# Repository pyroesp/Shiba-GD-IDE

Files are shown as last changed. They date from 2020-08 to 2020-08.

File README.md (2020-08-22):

# Shiba GD-IDE

The Sega Dreamcast uses a GD-ROM Optical Drive to read the game discs. Some clever people discovered that the optical drive uses connections similar to an IDE HDD.  
If you look for *Dreamcast HDD mod* on Google Images you'll see some crazy stuff. People were just soldering 40 pin flat ribbon cables to the motherboard or optical drive directly, which looks pretty cool to be honest.  

Some guys designed the GD-IDE which is a PCB, which is soldered on top of the optical drive of the Dreamcast, that allows you to plug in an IDE HDD.  
The Shiba GD-IDE is a complete redesign of GD-IDE board for the Toshiba GD-ROM Optical Drive.  

The name *Shiba GD-IDE* comes from the fact that the GD-ROM optical drive has a To**shiba** chip on it and the name of the original board. 

The original GD-IDE is designed by tawy / DragonCity.  
You can find the GD-IDE on DragonCity's webpage here: [Dreamcast GD-IDE](https://boutique-dragoncity.myshopify.com/collections/dreamcast/products/dreamcast-pcb-dreamcast-gd-ide-v3-connecteur-ide)

## Disclaimer

Obviously, I'm not responsible if this breaks your GD-ROM drive.  
At the time of writing (21/08/2020) the boards have not yet been tested.

## Compatible GD-ROM

The Shiba GD-IDE is only compatible with GD-ROM drive that have a Toshiba IC on top, like shown below.  
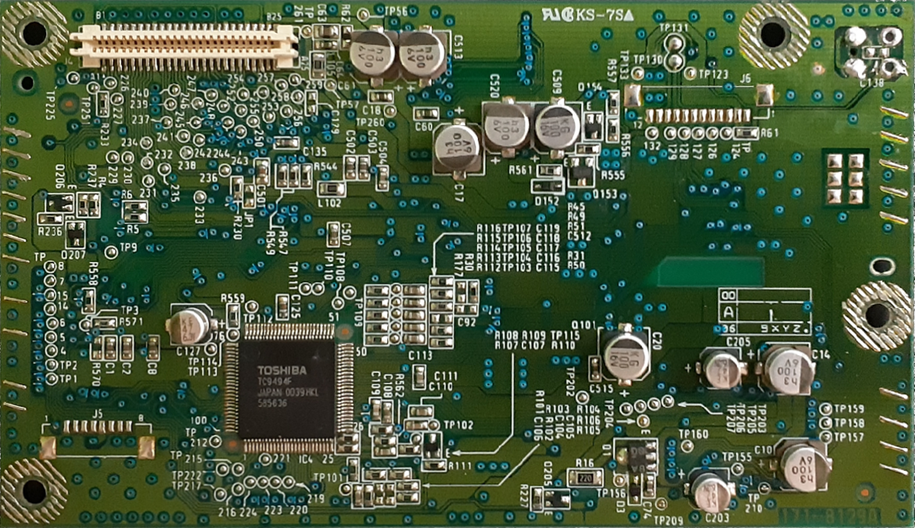
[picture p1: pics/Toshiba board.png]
  

## Shiba GD-IDE PCB

If you're going to buy some boards directly from a PCB fab, change the width of the board to 1mm.  
I'm using JLCPCB to make my boards and that's why I have added 'JLCJLCJLCJLC' on to the board as a place holder for their order number.  
It's kind of hidden under the 40 pin header, which is where I want it.  

Just like on the GD-IDE, you want to remove pin 20 from the header pins, to make it fit with DragonCity's ribbon cable.  

KiCad 3D model:  
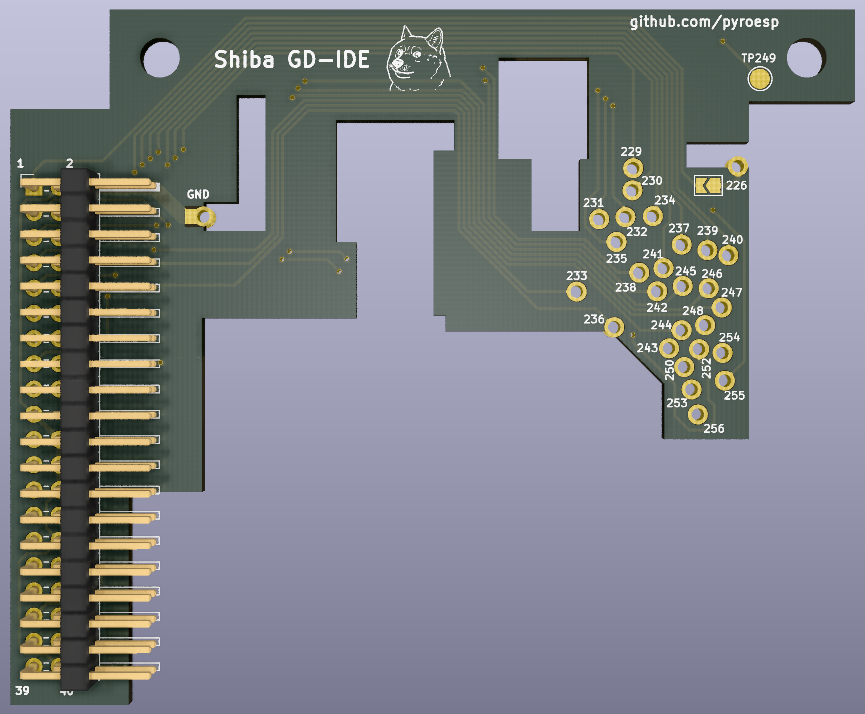
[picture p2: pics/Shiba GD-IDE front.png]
  

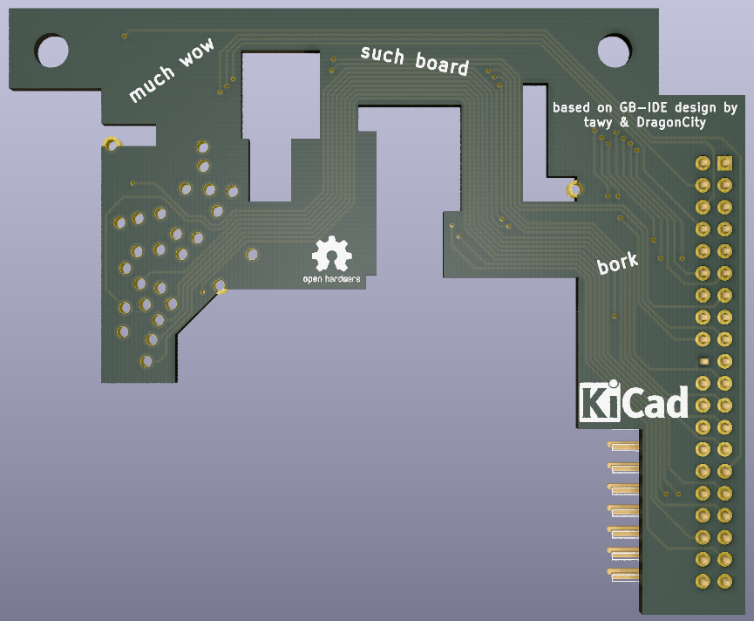
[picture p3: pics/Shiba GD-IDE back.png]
  

FreeCAD 3D model:  
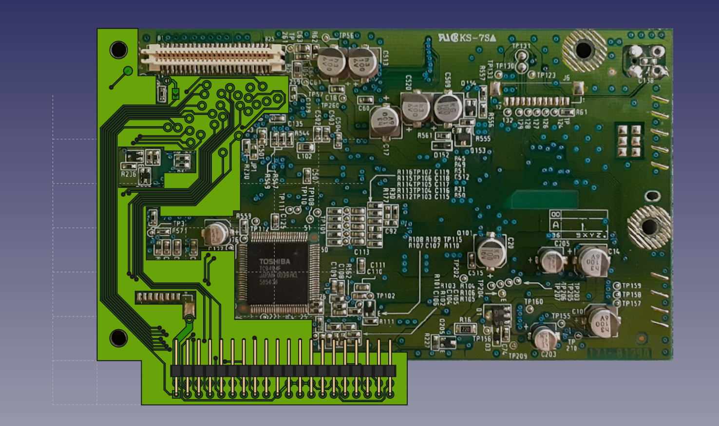
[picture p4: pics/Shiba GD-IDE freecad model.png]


## GD-ROM drive Connector

The connector is apparently a Molex 0525840579 that you can find on digikey.  
I got the names of the Molex connections from the schematics found on [console5.com](https://console5.com/wiki/Dreamcast).  
  
The connections from the Molex connector to the IDE HDD I got from DragonCity's image below.  
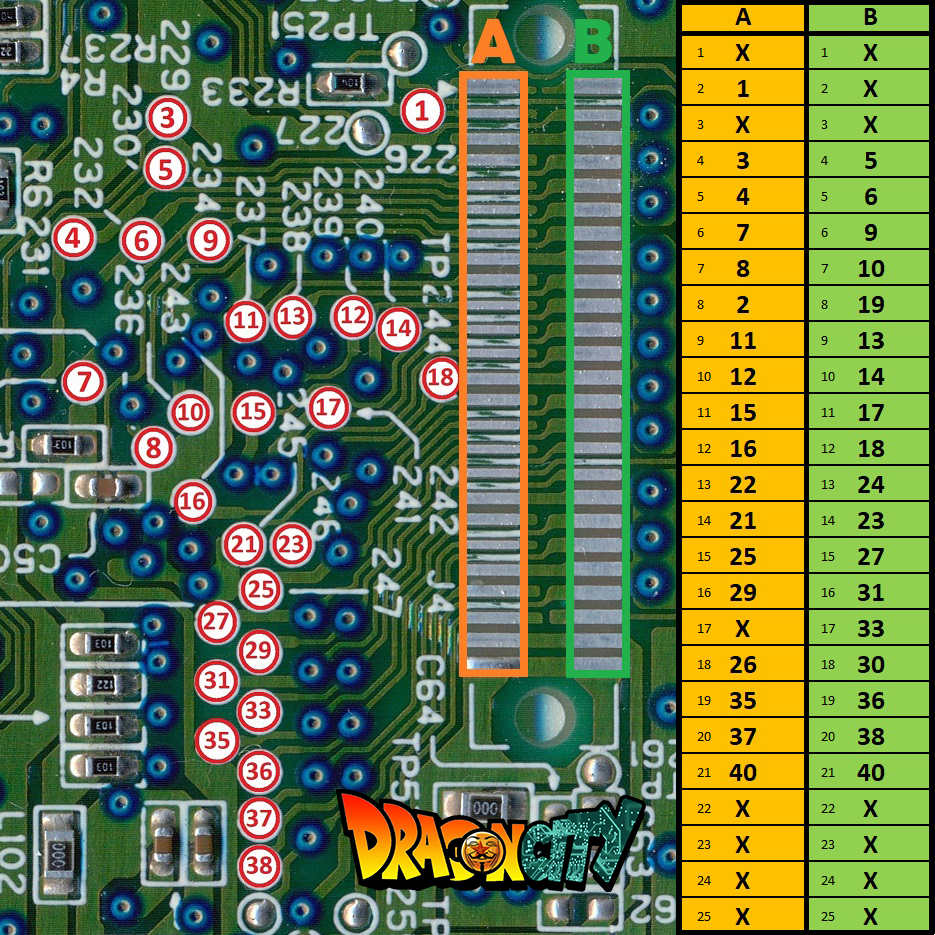
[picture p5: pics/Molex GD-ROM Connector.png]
  
*Note: I have added the smaller numbers into the two columns to make it easier for me to map

All pinouts, pin names and connections to test points can be found in the text file in the docs folder, which looks like this:  
> ...
> 
> IDE HDD to Dreamcast GD-ROM TP:
> -------------------------------
> IDE 1 - ~RESET		A2		TP226 (not needed but provide bridge, see install tutorial GD-IDE from Dragoncity.fr)  
> IDE 2 - GND		A8/GND  
> IDE 3 - HD7		A4		TP229  
> IDE 4 - HD8		A5		TP231  
> IDE 5 - HD6		B4		TP230  
> ...  

## BOM

- PCB from any PCB fab you want. I personnaly use JLCPCB as they're cheap.  
- IDE flat ribbon cable, like the one sold by DragonCity here: [IDE cable](https://boutique-dragoncity.myshopify.com/collections/dreamcast/products/nappe-ide-80-pins-ata-133)  
- Optional: [IDE to SATA adapter](https://boutique-dragoncity.myshopify.com/collections/dreamcast/products/adaptateur-ide-sata-jm20330-jp103-5) also sold by DragonCity  

## License

CC BY 4.0  
See LICENSE.md

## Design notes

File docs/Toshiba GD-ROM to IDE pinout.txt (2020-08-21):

Dreamcast GD-ROM connector:
---------------------------
A01 - 3.3V
A02 - G_RST
A03 - 5V
A04 - G1_D7
A05 - G1_RAD8
A06 - G1_D5
A07 - G1_RAD10
A08 - GND
A09 - G1_D3
A10 - G1_RAD12
A11 - G1_D1
A12 - G1_RAD14
A13 - GND
A14 - G1_BDRQ
A15 - G1_RDN
A16 - G1_DACKN
A17 - CD_EMPH
A18 - GND
A19 - G1_RAL8
A20 - G1_CS0N
A21 - GND
A22 - CD_BCK
A23 - CD_SD
A24 - P.GND
A25 - 12V

B01 - 3.3V
B02 - DOPEN
B03 - 5V
B04 - G1_D6
B05 - G1_RAD9
B06 - G1_D4
B07 - G1_RAD11
B08 - GND
B09 - G1_D2
B10 - G1_RAD13
B11 - G1_D0
B12 - G1_RAD15
B13 - GND
B14 - G1_WRN
B15 - G1_BIORDY
B16 - G1_BINTRQ
B17 - G1_RAL9
B18 - GND
B19 - G1_RAL10
B20 - G1_CS1N
B21 - GND
B22 - CD_LRCK
B23 - CDDA_CLK
B24 - P.GND
B25 - 12V

IDE HDD to Dreamcast GD-ROM TP:
-------------------------------
IDE 1 - ~RESET		A2		TP226 (not needed but provide bridge, see install tutorial GD-IDE from Dragoncity.fr)
IDE 2 - GND		A8/GND	
IDE 3 - HD7		A4		TP229
IDE 4 - HD8		A5		TP231
IDE 5 - HD6		B4		TP230
IDE 6 - HD9		B5		TP232
IDE 7 - HD5		A6		TP233
IDE 8 - HD10		A7		TP235
IDE 9 - HD4		B6		TP234
IDE 10 - HD11		B7		TP236
IDE 11 - HD3		A9		TP237
IDE 12 - HD12		A10		TP239
IDE 13 - HD2		B9		TP238
IDE 14 - HD13		B10		TP240
IDE 15 - HD1		A11		TP241
IDE 16 - HD14		A12		TP243
IDE 17 - HD0		B11		TP242
IDE 18 - HD15		B12		TP244
IDE 19 - GND		B8/GND		
IDE 20 - KEY		x		
IDE 21 - DMARQ		A14		TP245
IDE 22 - GND		A13/GND	
IDE 23 - IOWB		B14		TP246
IDE 24 - GND		B13/GND	
IDE 25 - IORB		A15		TP247
IDE 26 - GND		A18/GND	
IDE 27 - IORDY		B15		TP248
IDE 28 - NC		x		
IDE 29 - ~DMACK		A16		TP249 (back)
IDE 30 - GND		B18/GND	
IDE 31 - IREQ		B16		TP250
IDE 32 - IOIS16B	x		
IDE 33 - HA1		B17		TP252
IDE 34 - PDIAGB		x		
IDE 35 - HA0		A19		TP253
IDE 36 - HA2		B19		TP254
IDE 37 - CE1B		A20		TP255
IDE 38 - CE2B		B20		TP256
IDE 39 - DASPB		x		
IDE 40 - GND		A21/B21/GND

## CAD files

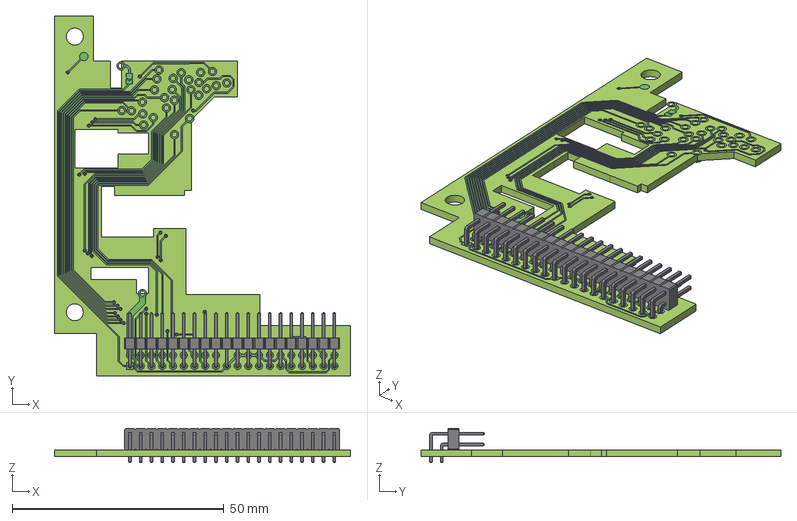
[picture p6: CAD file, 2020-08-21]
freecad/Toshiba GD-ROM.FCStd
70.0 x 85.0 x 8.08 mm
Pcb_39ca
topTracks_39ca
botTracks_39ca
J1_PinHeader_2x20_P254mm_Horizontal_5F3EEBF9

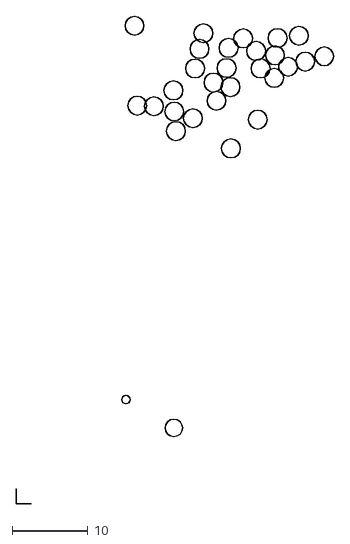
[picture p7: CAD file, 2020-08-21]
freecad/Toshiba GD-ROM IDE Test Points.dxf
42.0 x 64.5

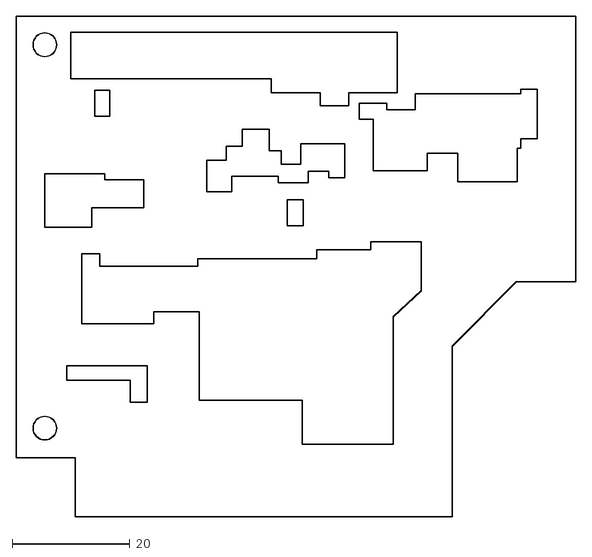
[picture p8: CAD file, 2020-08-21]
freecad/Toshiba GD-ROM IDE Board Outline.dxf
95.0 x 85.0

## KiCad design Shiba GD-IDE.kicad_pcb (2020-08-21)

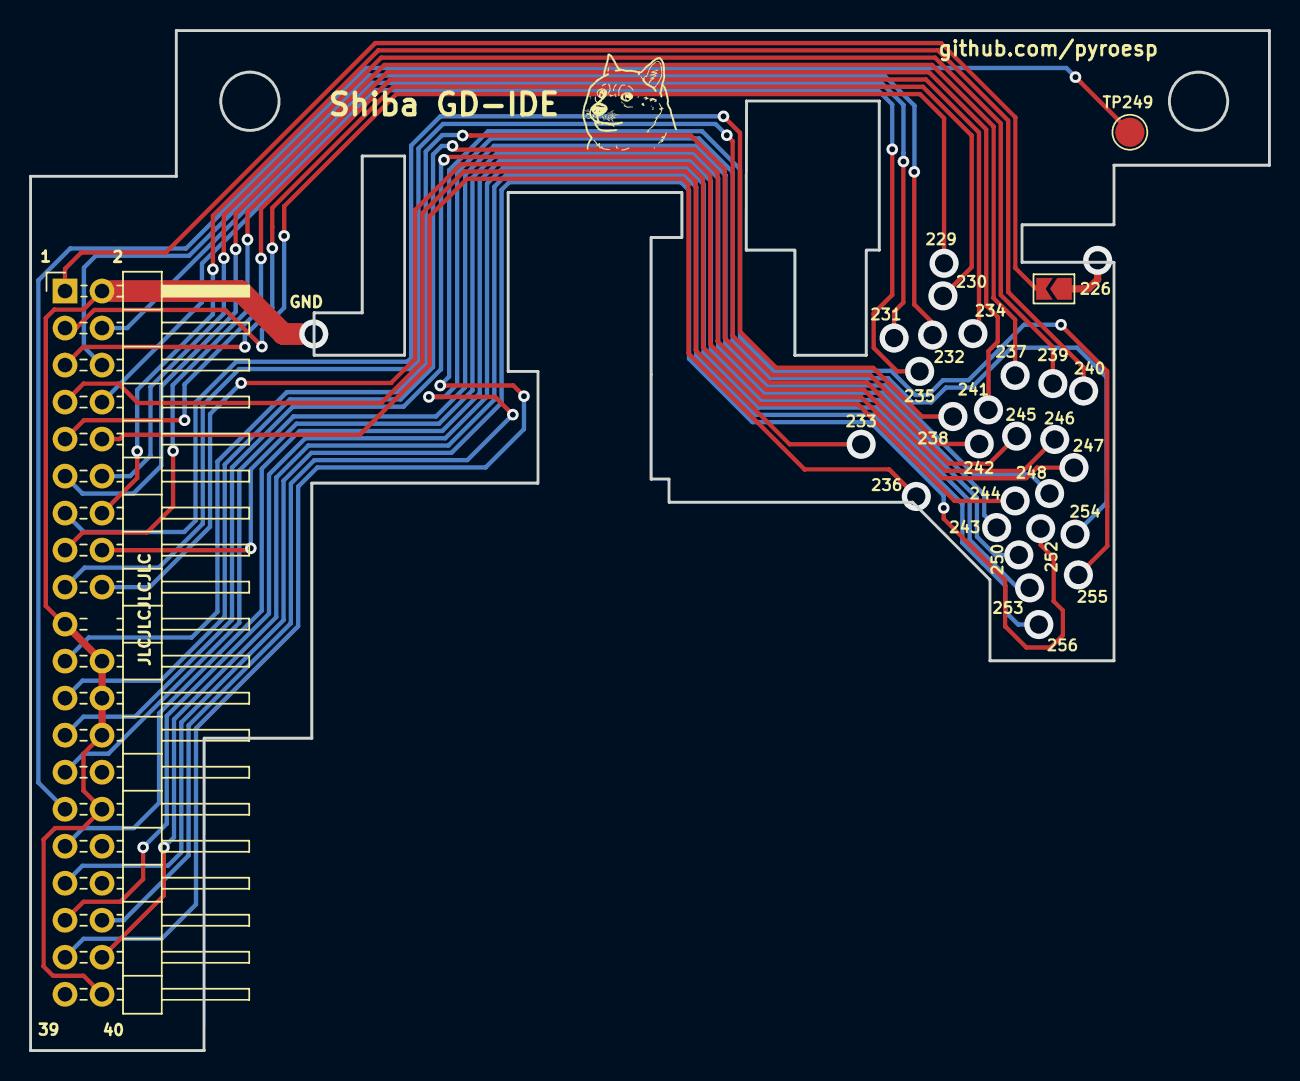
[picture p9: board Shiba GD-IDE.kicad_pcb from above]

Board: 2 copper layers, 85.0 x 70.0 mm, 3 parts (0 on the bottom side), 3 nets.

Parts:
J1: Conn_02x20_Odd_Even; PinHeader_2x20_P2.54mm_Horizontal
J2: SolderJumper-2_P1.3mm_Open_TrianglePad1.0x1.5mm
TP249: TestPoint_Pad_D2.0mm

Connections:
GND: J1.2, J1.19, J1.22, J1.24, J1.26, J1.30, J1.40
TP226: J1.1, J2.2
TP249: J1.29, TP249.1

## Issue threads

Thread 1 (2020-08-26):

Mounting holes

pyroesp, 2020-08-26:
Make mounting holes even bigger, compared to the optical driver board, for better placement of the Shiba board.

Currently set to 4mm, try 4.5mm.

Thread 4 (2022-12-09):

Doesn't work

dragoncity17, 2022-12-09:
Hello,
I decided to test (yes difficult because I have a lot of work to do ^^).

But doesn't work, did you work for you ?

Block at boot.

Maybe a component who block ATA....

I checked all your point it's ok, so it's not your PCB I think, but like say before an incompatibility....

pyroesp, 2022-12-09:
Hi @dragoncity17,
I've only ever tested this on my own dreamcast and haven't heard anything from other users (if there are any).
It was not easy to get it to work as I believe it's very sensitive to noise.
In the end, I got it working after trying 3 different IDE cables.

Maybe a board revision is needed to improve/reroute the traces, but I haven't really looked at this since I first made it.

dragoncity17, 2022-12-10:
Hum étrange, tu as réussi avec ta PCB donc ?
Car moi impossible de booter, ça bloque.... et j'ai testé sur 2 GDROM différents ! ^^

Car on est bien d'accord à part souder les pastilles, et le point en haut à droite à la Pin 29 c'est tout ce qu'il y a à faire ?

De toute façon j'ai contrôlé pin par pin... d'où le fait que je ne comprenne pas si tu me dis que chez toi ça fonctionne...

Je pensais vraiment qu'un composant bloquait.

Car la nappe IDE et l'adaptateur IDE/SATA si je les mets sur un autre GDROM compatible cette fois-ci GD-IDE ça fonctionne, donc je suis sur de la nappe et de l'adaptateur... o_O

Désolé je te l'ai fait en français c'était plus rapide pour moi et ça évite que je traduise des bêtises ^^ !

pyroesp, 2022-12-10:
Oui j'avais réussi avec le mien.
J'ai eu le même souci de boot, mais vu que le PCB et les connections étaient correctes j'ai décidé d'utiliser different cables IDE.
Et après le 3em ça à marché.

Je ne me souviens pas si c'était le pin29 du chip à l'arrière, mais d'après la doc que j'avais écrit c'est le test point TP249 à l'arrière.

Je suis sur que les nappes sont bonnes et fonctionnes, mais je pense que c'est très susceptible aux interférences et du coup c'est difficile à faire fonctionner.
J'ai pas vraiment fait attention aux connections quand j'ai fait les traces sur le PCB et peut-être pour ça que certains signaux interfèrent l'un à l'autre... ?

D'après mes achats ebay, la nappe qui a fonctionné c'est une "_Nappe IDE ATA 133/100/66 45cm Câble IDE Pour Périphériques PC_".

Depuis le temps mon dualboot a grillé et j'ai rangé la dreamcast. J'y ai pas touché depuis.

C'est embêtant que tu n'arrives pas à le faire fonctionner.
J'ai probablement eu beaucoup de chance que ça ai marché chez moi du coup...

Je ne peux que te conseiller d'utiliser d'autres nappes, ou essayer d'isoler (avec blindage?) au plus possible la nappe du GD-ROM, pour minimiser les interférences.

dragoncity17, 2022-12-10:
Oui c'est bien ce point même si j'ai pris directement sur le GDROM ou un autre point a l'arrière.

Bon quand j'aurai du temps je regarderai de nouveau :)

Closed 2023-02-04.

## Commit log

2020-08-21 Shiba GD-IDE first commit
    [Shiba GD-IDE.kicad_pcb, Shiba GD-IDE.sch]
2020-08-21 gerber files first commit
    [Shiba GD-IDE-B_Cu.gbr, Shiba GD-IDE-B_Mask.gbr, Shiba GD-IDE-B_SilkS.gbr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]
2020-08-21 added freecad files
    [Toshiba GD-ROM IDE Board Outline.dxf, Toshiba GD-ROM IDE Test Points.dxf, Toshiba GD-ROM.FCStd]
2020-08-21 Toshiba GD-ROM board picture
2020-08-21 GD-ROM Molex connector pinout from DragonCity
2020-08-21 updated freecad model
    [Toshiba GD-ROM.FCStd]
2020-08-21 added pics of the Shiba GB-IDE PCB
